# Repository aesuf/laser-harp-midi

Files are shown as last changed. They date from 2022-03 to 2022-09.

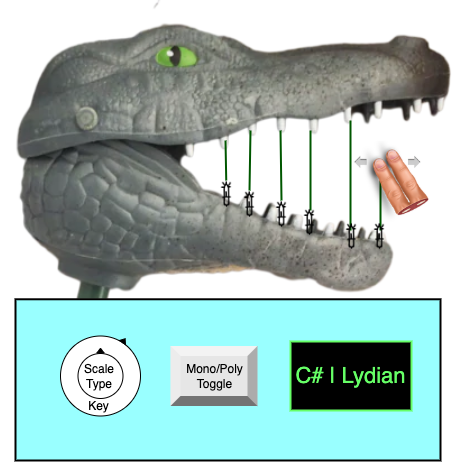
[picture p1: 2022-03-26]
LaserHarp.drawio.png

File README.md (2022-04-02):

# Laser Harp MIDI Controller
*UF AES's 2022 Hardware Project*
## Project Inspiration and Summary 
Laser harps, also known as light harps, are musical instruments which use light or laser beams as "strings" and were originally inspired by the harp. The first laser harps were invented in the late 70s and early 80s by musicians and inventors Geoffrey Rose and Bernard Szajner. Over time, laser harps have taken more unique shapes and used various  methods to detect broken light beams. Some of these methods include using mirrors and sensors, image processing with high speed cameras, and simple sensors such as photoresistors. The overall designs vary from traditional harp look-a-likes to cubes of lasers to frameless styles.

For our project, we decided to create a framed laser harp using lasers and phototransitors. This implementation differs from many other online laser harp projacts as our design is a MIDI controller built to work with our previous synthesizer projects. Our goals were to further our understanding of power supply design, sensor implementation and control, circuit design, microprocessor programming, and CAD modeling. 

Further technical details can be found in the `MidiLaserLightHarp.docx` file.

## Parts List
* Teensy 4.1 (1)
* Green Lasers (8)
* Phototransistors (8)
    * Resistors (8)
* Linear Power Regulator
* Rotary Encoders (2)

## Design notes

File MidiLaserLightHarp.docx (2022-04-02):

OBJECTIVE

Design and construct a robust a robust project to further our understanding different electrical engineering disciplines: power supply design, sensor implementation and control, circuit design, microprocessor programming, and CAD.

DESIGN

We began by putting together a basic outline Fig. 1 of our project which was subject to change as we advanced through the design process

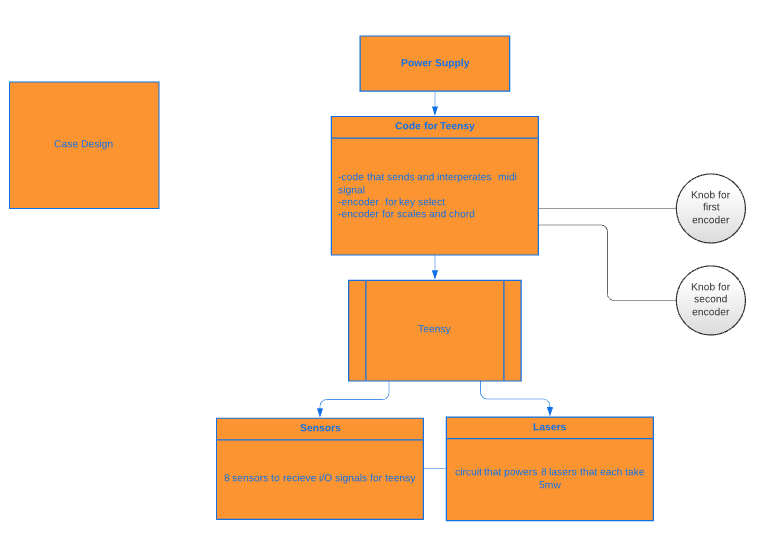
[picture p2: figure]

Fig 1. Hypothesized design for Midi Laser Light Harp

INTRODUCTION

- In order to pursue this project we needed to build a power supply to power the system, a microcontroller to control take I/O signals and generate an output, lasers and sensors to generate I/O signals, and two knobs encoders for pitch selection and to select between single notes or chord transposition.

POWER SUPPLY

The intended purpose of this power supply was to serve as a bus for multiple projects. Therefore, our power supply needed to have three outputs: +12 and -12 volts for our analog synthesizer and +5V for our midi laser light harp.

Input taken from data sheet

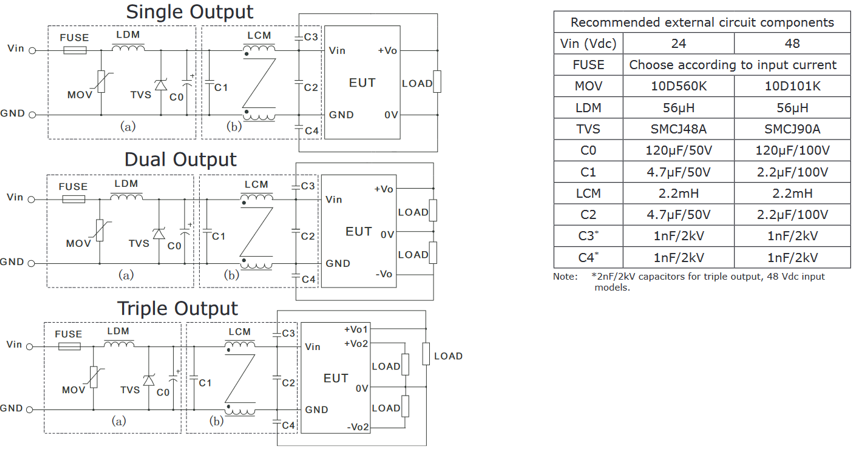
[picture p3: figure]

Figure 2. Options for power supply configurations based on datasheet, dual output was selected

Output filter based off a basic LC filter that is 10x below the frequency of a converter

CODE FOR TEENSY

The code for our teensy used the Arduino programming language. This language was chosen because it has pre-built midi libraries. The purpose of the code is to monitor the pins hooked up to the sensors to monitor for a note being played. Stored in memory is a set of configurations (major scale/minor scale/chord) for each supported base note (C, D, etc.). The configuration is chosen by the input from the rotary encoders. Once the code determines that a note has been played (beam of light has been interrupted), it outputs the desired note. The output is done via midi. Midi output includes which note is being played, as well as when to start and stop the note.

TEENSY

We chose to use a Teensy for this project because it supports the pre-built midi libraries available for Arduino. We used a teensy instead of Arduino because it offered the same functionality at a lower cost. Requirements for the microprocessor were enough GPIO pins to read the input from the 7 laser sensors. In addition, it needed to support the input from two encoding knobs. We also needed a small amount of memory to hold the different harp configurations (major scale/minor scale/chord for each base note).

ENCODERS

In addition to input for the strings, we needed a way to select which notes would be controlled by which string. To do this, we implanted two rotary encoders. For this project, we chose to use [absolute/incremental] encoders. These allowed us to scroll through a set of note configurations for the harp (i.e. whether the strings compromise the notes of a scale or notes of a chord) as well as the base note for the scale/chord (e.g. C major, D minor, etc.).

LASERS

The lasers work with the sensors to provide input to the laser harp. The lasers form the “strings” of the harp, and notes are played by interrupting the beam between the laser and the sensor. For safety reasons, we chose lasers with output less than 5mW. Green lasers were chosen as they allow for a more easily visible beam. For this design, we chose to implement 7 lasers, allowing for a full octave major scale.

SENSORS

The sensors work with the lasers to provide input to the microcontroller. We chose phototransistors as they were cheaper and easier to integrate with GPIO. As part of the sensor design, we chose to embed the sensors in the case and cover them with wax paper in order to filter out ambient light. The sensors expect a constant laser beam light source when no note is being played. In order to play a note, the beam of light between the sensor and laser emitter is interrupted. The microcontroller constantly monitors the input, and when the beam is interrupted it outpus a signal to being playing the note. The note remains played until the beam of light is restored.

CASE DESIGN

The encloser must hold the components, including the teensy and power supply. It also houses the lasers and sensors with a gap between them for the laser beams. The gap allows for the strumming of the laser “strings” emulating how one would play a traditional harp. The primary structure was composed of [wood/plastic] due to the lower cost. The enclosure was designed using the CAD software SolidWorks.

University of Florida Midi Laser Light Harp Audio Engineering Society Electrical & Computer Engineering Dept. Page 1/5 Spring 2022

University of Florida EEL3744C – Microprocessor Applications Last Name, First Name Electrical & Computer Engineering Dept. Lab # Report: Lab Title Section: <5-digit class id> (<4-digit section>) Page 1/5 Revision: X Month Day, Year

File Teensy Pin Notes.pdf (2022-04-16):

## Teensy 4.1 Pin Notes

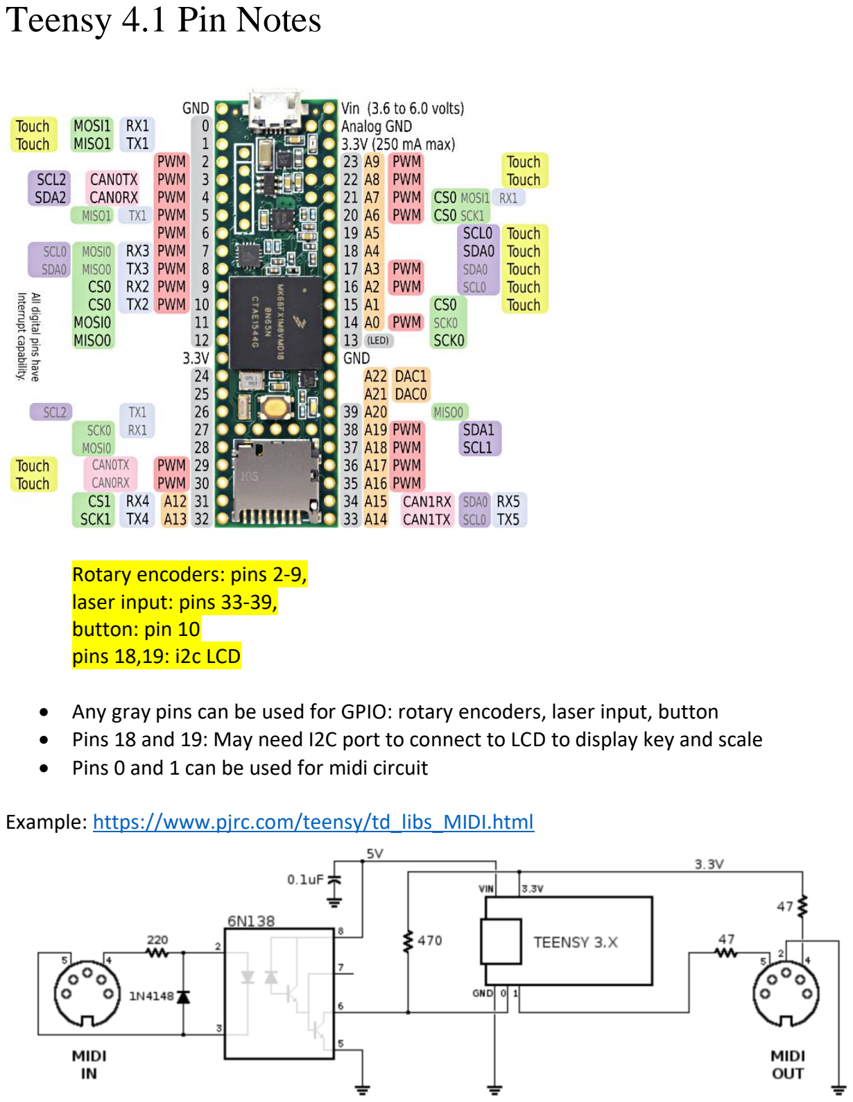
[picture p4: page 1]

Rotary encoders: pins 2-9, laser input: pins 33-39,
button: pin 10
pins 18,19: i2c LCD
- Any gray pins can be used for GPIO: rotary encoders, laser input, button
- Pins 18 and 19: May need I2C port to connect to LCD to display key and scale
- Pins 0 and 1 can be used for midi circuit

Example: https://www.pjrc.com/teensy/td_libs_MIDI.html

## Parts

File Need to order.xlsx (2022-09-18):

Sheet: Need to Order
Part | Quantity | Price | Link
Encoder | 2 | $1.78 | https://www.digikey.com/en/products/detail/bourns-inc/PEC11R-4215F-N0024/4499663
Photodiodes | 8 | $0.67 | https://www.digikey.com/en/products/detail/excelitas-technologies/VTP9812FH/5885875
Encoder Knob | 2 | $0.76 | https://www.newark.com/multicomp/cp-aa19a-d-6-4-b6/shaft-type-d-shaft/dp/73M9570
Display | 1 | $9.19 | https://www.amazon.com/HiLetgo-128x64-SSH1106-Display-Arduino/dp/B01N1LZT8L
Linear Regulator | 2 | $4.75 | https://www.digikey.com/en/products/detail/microchip-technology/MIC29150-3-3WT/771573
Switch | 2 | $3.53 | https://www.newark.com/e-switch/r5bblkgrnff2/switch-rocker-dpst-20a-125vac/dp/15N9104
Total | $36.19

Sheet: Total BOM
Part | Quantity | Price | Link
Encoder | 2 | $1.78 | https://www.digikey.com/en/products/detail/bourns-inc/PEC11R-4215F-N0024/4499663
Photodiodes | 8 | $0.67 | https://www.digikey.com/en/products/detail/excelitas-technologies/VTP9812FH/5885875
Lasers | 8 | $7.00 | ebay
Encoder Knob | 2 | $0.76 | https://www.newark.com/multicomp/cp-aa19a-d-6-4-b6/shaft-type-d-shaft/dp/73M9570
Display | 1 | $9.19 | https://www.amazon.com/HiLetgo-128x64-SSH1106-Display-Arduino/dp/B01N1LZT8L
Linear Regulator | 2 | $4.75 | https://www.digikey.com/en/products/detail/microchip-technology/MIC29150-3-3WT/771573
Switch | 2 | $3.53 | https://www.newark.com/e-switch/r5bblkgrnff2/switch-rocker-dpst-20a-125vac/dp/15N9104
Total | $92.19

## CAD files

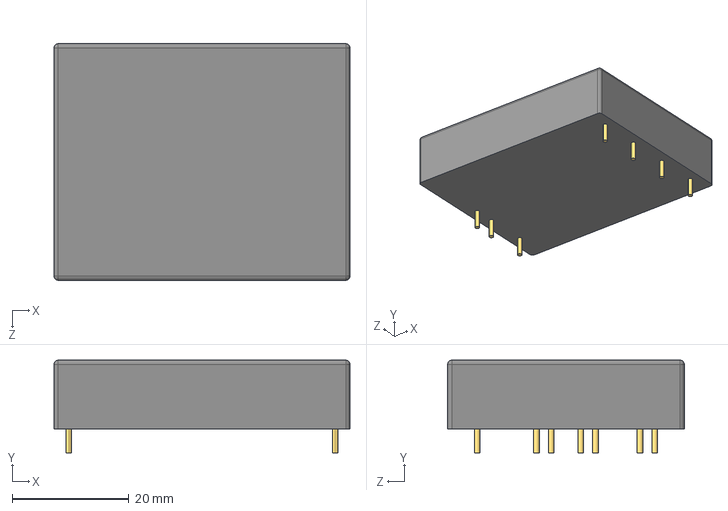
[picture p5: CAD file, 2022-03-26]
Altium/footprints/DCConverterPYB30-Q24-D12--3DModel.STEP
50.8 x 15.9 x 40.6 mm

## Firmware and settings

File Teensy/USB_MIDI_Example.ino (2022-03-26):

/* Simple Teensy DIY USB-MIDI controller.
  Created by Liam Lacey, based on the Teensy USB-MIDI Buttons example code.

   Contains 8 push buttons for sending MIDI messages,
   and a toggle switch for setting whether the buttons
   send note messages or CC messages.

   The toggle switch is connected to input pin 0,
   and the push buttons are connected to input pins 1 - 8.

   You must select MIDI from the "Tools > USB Type" menu for this code to compile.

   To change the name of the USB-MIDI device, edit the STR_PRODUCT define
   in the /Applications/Arduino.app/Contents/Java/hardware/teensy/avr/cores/usb_midi/usb_private.h
   file. You may need to clear your computers cache of MIDI devices for the name change to be applied.

   See https://www.pjrc.com/teensy/td_midi.html for the Teensy MIDI library documentation.

*/
#define NUM_OF_BUTTONS 8
#define MS_DELAY 500

// the MIDI channel number to send messages
const int MIDI_CHAN = 1;


const int MIDI_MODE_NOTES = 0;
const int MIDI_MODE_CCS = 1;

//Variable that stores the current MIDI mode of the device (what type of messages the push buttons send).
int midiMode = MIDI_MODE_NOTES;

//Arrays the store the exact note and CC messages each push button will send.
const int MIDI_NOTE_NUMS[NUM_OF_BUTTONS] = {64, 66, 68, 69, 71, 73, 75, 76};
const int MIDI_NOTE_VELS[NUM_OF_BUTTONS] = {110, 110, 110, 110, 110, 110, 110, 110};
const int MIDI_CC_NUMS[NUM_OF_BUTTONS] = {24, 25, 26, 27, 20, 21, 22, 23};
const int MIDI_CC_VALS[NUM_OF_BUTTONS] = {127, 127, 127, 127, 127, 127, 127, 127};

//==============================================================================
//==============================================================================
//==============================================================================
//The setup function. Called once when the Teensy is turned on or restarted

void setup()
{

}

//==============================================================================
//==============================================================================
//==============================================================================
//The loop function. Called over-and-over once the setup function has been called.

void loop()
{
  
  for(int i = 0; i < NUM_OF_BUTTONS; i++){
//    usbMIDI.sendControlChange (MIDI_CC_NUMS[i], MIDI_CC_VALS[i], MIDI_CHAN);
//    delay(MS_DELAY);

    usbMIDI.sendNoteOn (MIDI_NOTE_NUMS[i], 110, MIDI_CHAN);
    delay(100);
    usbMIDI.sendNoteOff (MIDI_NOTE_NUMS[i], 0, MIDI_CHAN);
    delay(MS_DELAY);
//    usbMIDI.sendControlChange (MIDI_CC_NUMS[i], 0, MIDI_CHAN);
//    delay(1000);
//    while (usbMIDI.read())
//    {
//      // ignoring incoming messages, so don't do anything here.
//    }
  }
}

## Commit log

2022-02-26 Added altium powerBus and Excel spreadsheet
    [Need to order.xlsx, powerBus.PrjPcb, powerBus_Sch.SchDoc]
2022-02-26 sensors and lasers schematic
    [lasers.SchDoc, sensors.SchDoc]
2022-02-26 added encoder and phototransistor links from discord into the need to order file
    [Need to order.xlsx]
2022-02-26 sensors and lasers schematics
    [lasers.SchDoc, sensors.SchDoc]
2022-02-26 Updated Altium Schematic
    [powerBus.PrjPcb, powerBus_Sch.SchDoc]
2022-03-05 added encoder footprint
    [Laser-Harp.PrjPcb, SamacSys.PcbLib, SamacSys.SchLib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]
2022-03-19 updated powerbus
    [powerBus_Sch.SchDoc]
2022-03-19 Ryan added footprints
    [10_uf_100V_x7r_CAPC5750X330N.PcbLib, 2100LL-560-H-RC.PcbLib, 2100LL-560-H-RC.SchLib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]
2022-03-19 adding pcb powerbus
    [PCB1.PcbDoc, Sheet1.SchDoc, powerBus.PrjPcb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]
2022-03-26 new sheet
    [Laser-Harp.PrjPcb, knobs-and-teensy.SchDoc]
2022-03-27 updated pcb
    [PCB1.PcbDoc, powerBus_Sch.SchDoc]
2022-04-10 Routed PowerBus PCB
    [PCB1.PcbDoc, Sheet1.SchDoc, powerBus.PrjPcb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]
2022-04-10 Added Copper Pours
    [PCB1.PcbDoc, powerBus.PrjPcb]
